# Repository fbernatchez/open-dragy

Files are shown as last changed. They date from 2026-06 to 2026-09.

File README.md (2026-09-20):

# 🏁 OpenDragy

OpenDragy is a high-precision, open-source vehicle performance timer that measures acceleration, speed intervals, and distances. It combines custom **ESP32-S3 firmware** reading a 10Hz GPS and a BMI160 accelerometer with a sleek, dark-themed **Flutter companion app** over Bluetooth Low Energy (BLE).

---

## ✨ Features

* **High-Precision Telemetry (10Hz)**: Receives and parses binary **UBX-NAV-PVT** packets from the u-blox GPS module 10 times per second, providing precise speed, position, and satellite count directly from the chip's internal navigation solution.
* **Real-Time G-Force Telemetry**: Streams live accelerometer data at 100Hz from the onboard BMI160 IMU for instant G-force mapping and post-run acceleration curve analysis.
* **Flexible Mounting & 3D Attitude Alignment**: Mount the enclosure facing any direction (0–359°) and on sloped surfaces (windshield mounts, angled dashboards, cup holders). Continuous 3D gravity vector tracking ($A_x, A_y, A_z$) projects acceleration onto the true horizontal plane orthogonal to gravity, preventing cosine attenuation and eliminating pitch/roll slope leakage.
* **Interactive Mounting Preview**: An intuitive graphical setup dialog renders a top-down view of the OpenDragy enclosure rotating dynamically over a neutral compass rose with 0°, 90°, 180°, 270° quick presets and 1° fine-tuning.
* **Zero-Crossing Interpolation**: Interpolates the exact start time (down to the millisecond) between the last stationary tick and the first launch tick, guaranteeing highly accurate launch timings.
* **Auto-Armed Launch Control**: Automatically starts recording when speed exceeds `3.0 km/h` to bypass GPS drift/wandering, auto-stops when stationary, and auto-disarms upon completion.
* **Voice Announcements (TTS) & Audio Recording**: Real-time spoken announcements for run starts, milestone completions, and trap speeds. Optional cabin audio recording lets you capture exhaust notes synced directly with your telemetry.
* **Wireless OTA Firmware Updates**: Wirelessly check for, download, and flash ESP32-S3 firmware updates directly over BLE from the companion app without opening the case or plugging in USB.
* **Wakelock Integration**: Intelligently keeps your device screen awake and active during armed and ongoing runs, so you never miss your telemetry.
* **Aesthetic Companion App**: Built with Flutter featuring a premium OLED black design with Neon Amber and Neon Green styling, utilizing the Inter font family.
* **Garage & Fleet Management**: Track multiple vehicles locally and link performance runs to specific cars or bikes.
* **Automated Weather Logging**: Uses coordinates from the GPS at the time of the run to fetch ambient temperature, altitude, and relative humidity from the free Open-Meteo API.
* **Run Database & Analytics**: View historical runs with detailed interactive charts showing speed curves, G-force mapping, and elevation/slope profiles to ensure valid runs.

---

## 🏎️ Supported Run Types & Targets

### Drag Mode (From a standstill)
* **Distances**: 60ft, 330ft, 1/8 mile, 1000 ft, 1/4 mile, 1/2 mile (includes trap speed calculations)
* **Speeds**: 0-60 mph, 0-100 km/h, 0-130 mph, 0-200 km/h
* **NHRA Mode**: Optional 1-ft rollout subtraction and 66ft average trap speed calculation to match official track times.

### Interval Mode (Speed-to-Speed)
* **Standard Ranges**:
  * **Imperial**: 0-60 mph, 0-100 mph, 50-75 mph, 60-100 mph, 60-130 mph, 0-130 mph
  * **Metric**: 0-100 km/h, 0-160 km/h, 80-120 km/h, 100-160 km/h, 100-200 km/h, 0-200 km/h
* **Custom Ranges**: Define your own starting and ending speeds (e.g., 100-150 km/h, 80-120 km/h) in both Metric and Imperial units.

---

## 🛠️ Hardware Setup

The hardware unit runs on an **ESP32-S3** microcontroller that interfaces with a high-speed GPS module and a 6-axis IMU sensor.

For a 3D-printable case for the OpenDragy hardware, check out the [OpenDragy Printables page](https://www.printables.com/model/1762658-opendragy-open-source-high-precision-10hz-gps-perf).

### 📋 Bill of Materials (BOM)
1. **ESP32-S3 Mini Development Board** (or similar ESP32-S3 board)
2. **QUESCAN G10A-F30 UBX M10 GPS Module** (supporting 10-25Hz refresh rates and configured at 115200 baud)
3. **BMI160 Accelerometer/Gyroscope IMU Module** (connected via I2C)

### 🔌 Pin Connections
Connect the components to your ESP32-S3 board using the following pin mapping defined in the firmware:

| Component | Component Pin | ESP32-S3 Pin | Notes |
| :--- | :--- | :--- | :--- |
| **BMI160 IMU** | VCC | 3.3V | Power supply |
| | GND | GND | Ground |
| | SDA | **GPIO 1** | I2C Data line |
| | SCL | **GPIO 2** | I2C Clock line |
| **u-blox GPS** | VCC | 3.3V or 5V | Power supply (depending on module) |
| | GND | GND | Ground |
| | TX | **GPIO 4** | Connects to ESP32-S3 RX (UART1) |
| | RX | **GPIO 5** | Connects to ESP32-S3 TX (UART1) |

---

## 💾 Firmware Installation

The ESP32-S3 firmware is located in [`OpenDragy.ino`](OpenDragy.ino).

1. Install the Arduino IDE or VS Code with the PlatformIO extension.
2. Install the **ESP32 board support package** if using Arduino IDE.
3. Install the library dependencies:
   * **DFRobot_BMI160** library (for interfacing with the IMU)
   * **BLE** stack (built-in for ESP32/ESP32-S3)
4. Open [`OpenDragy.ino`](OpenDragy.ino).
5. Compile and flash the code to your ESP32-S3.
6. The device will boot and start broadcasting a BLE service named `OpenDragy`.

---

## 📱 Mobile App Setup

The companion application is written in Flutter and is located in the root directory.

### Prerequisites
* Flutter SDK (v3.11.5 or newer recommended)
* Android Studio (for Android build) / Xcode (for iOS build, macOS required)
* A physical device with Bluetooth enabled (BLE is not supported on most simulators/emulators)

### Getting Started

1. Get packages and dependencies:
   ```bash
   flutter pub get
   ```

2. Run the application on a connected device:
   ```bash
   flutter run --release
   ```
   *(Running in release mode is recommended for accurate performance and UI timing).*

---

## 📂 Code Structure

* [`OpenDragy.ino`](OpenDragy.ino): Microcontroller C++ firmware for reading binary UBX-NAV-PVT packets over UART & I2C IMU data and transmitting over BLE.
* [`lib/main.dart`](lib/main.dart): Main application entry point, sets up global theme and screen routing.
* [`lib/services/physics_engine.dart`](lib/services/physics_engine.dart): Advanced physics computations (trapezoidal integration, zero-crossing interpolation, speed interval timing).
* [`lib/services/ble_service.dart`](lib/services/ble_service.dart): BLE scanner and stream listener that parses binary UBX packets & IMU data.
* [`lib/providers/dragy_provider.dart`](lib/providers/dragy_provider.dart): Core state provider coordinating Bluetooth events, GPS/IMU data processing, 3D attitude alignment, run logic, settings, and database saves.
* [`lib/services/history_service.dart`](lib/services/history_service.dart): Manages local saving and retrieval of historical run logs.
* [`lib/services/weather_service.dart`](lib/services/weather_service.dart): Integration with Open-Meteo API to log run-time environment data.
* [`lib/services/garage_service.dart`](lib/services/garage_service.dart): Manages local storage of vehicle profiles (cars, bikes) for fleet management.
* [`lib/services/settings_service.dart`](lib/services/settings_service.dart): Handles user preferences such as unit toggles (Metric/Imperial) and app settings.
* [`lib/services/tts_service.dart`](lib/services/tts_service.dart): Voice announcements (TTS) for run starts, milestone completions, and trap speeds.
* [`lib/services/audio_recording_service.dart`](lib/services/audio_recording_service.dart): Cabin audio recording synchronized with telemetry during performance runs.
* [`lib/services/firmware_service.dart`](lib/services/firmware_service.dart): Manages ESP32-S3 firmware version checks and wireless OTA updates over BLE.
* [`lib/widgets/box_pivot_preview.dart`](lib/widgets/box_pivot_preview.dart): Interactive 360° enclosure orientation dialog with rotating top-down visual preview, presets, and fine slider.
* [`lib/screens/dashboard_screen.dart`](lib/screens/dashboard_screen.dart): Live telemetry display, speedometer, Bluetooth controls, and active timer stats.
* [`lib/screens/run_history_screen.dart`](lib/screens/run_history_screen.dart): Displays the history of all recorded runs and allows filtering or selecting runs to view details.
* [`lib/screens/run_detail_screen.dart`](lib/screens/run_detail_screen.dart): Post-run analysis, graphs, G-force curves, and slope validations.
* [`lib/screens/garage_screen.dart`](lib/screens/garage_screen.dart): Interface for adding, editing, and selecting vehicles.
* [`lib/screens/settings_screen.dart`](lib/screens/settings_screen.dart): UI for configuring app preferences, box pivot orientation, audio settings, and OTA firmware.

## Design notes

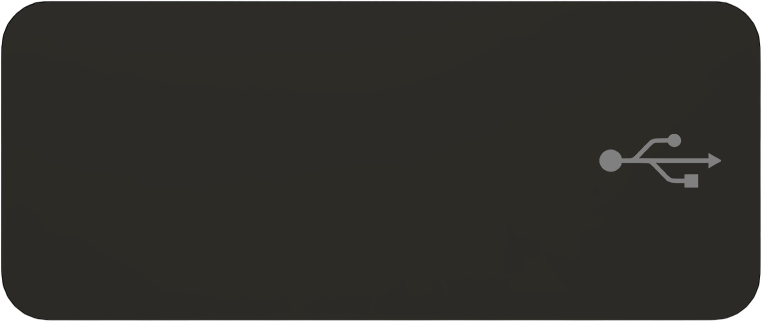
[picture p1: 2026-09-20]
assets/images/box-top-view.png

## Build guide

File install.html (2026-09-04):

# Flash OpenDragy

Connect your ESP32-S3 via USB, select a firmware version, and click Install to flash your device directly from the browser.

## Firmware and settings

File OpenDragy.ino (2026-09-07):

#include <Arduino.h>
#include <BLE2902.h>
#include <BLEDevice.h>
#include <BLEServer.h>
#include <BLEUtils.h>
#include <DFRobot_BMI160.h>
#include <HardwareSerial.h>
#include <Update.h>
#include <Wire.h>

HardwareSerial UART(1);
DFRobot_BMI160 bmi160;

BLEServer *pServer = NULL;
BLECharacteristic *pTxCharacteristic = NULL;
BLECharacteristic *pImuCharacteristic = NULL;

volatile bool deviceConnected = false;
volatile bool oldDeviceConnected = false;
bool imuReady = false;
bool otaRebootPending = false;

#define SERVICE_UUID "6e400001-b5a3-f393-e0a9-e50e24dcca9e"
#define CHARACTERISTIC_UUID_RX "6e400002-b5a3-f393-e0a9-e50e24dcca9e"
#define CHARACTERISTIC_UUID_TX "6e400003-b5a3-f393-e0a9-e50e24dcca9e"
#define CHARACTERISTIC_UUID_IMU "6e400004-b5a3-f393-e0a9-e50e24dcca9e"
#define CHARACTERISTIC_UUID_VERSION "6e400005-b5a3-f393-e0a9-e50e24dcca9e"
#define CHARACTERISTIC_UUID_OTA_CTRL "6e400006-b5a3-f393-e0a9-e50e24dcca9e"
#define CHARACTERISTIC_UUID_OTA_DATA "6e400007-b5a3-f393-e0a9-e50e24dcca9e"

#define FIRMWARE_VERSION "1.0.3"

// RTOS Queue for GPS packets
QueueHandle_t gpsQueue;

class MyServerCallbacks : public BLEServerCallbacks {
  void onConnect(BLEServer *pServer) {
    deviceConnected = true;
    pServer->updateConnParams(pServer->getConnId(), 0x06, 0x12, 0, 100);
  };
  void onDisconnect(BLEServer *pServer) { deviceConnected = false; }
};

class MyCallbacks : public BLECharacteristicCallbacks {
  void onWrite(BLECharacteristic *pCharacteristic) {
    String rxValue = pCharacteristic->getValue();
    if (rxValue.length() > 0) {
      UART.write((uint8_t *)rxValue.c_str(), rxValue.length());
    }
  }
};

class OtaCtrlCallbacks : public BLECharacteristicCallbacks {
  void onWrite(BLECharacteristic *pCharacteristic) {
    String rxValue = pCharacteristic->getValue();
    if (rxValue.length() > 0) {
      uint8_t cmd = rxValue[0];
      if (cmd == 0x00) { // Start OTA
        if (rxValue.length() >= 5) {
          uint32_t fwSize = rxValue[1] | (rxValue[2] << 8) |
                            (rxValue[3] << 16) | (rxValue[4] << 24);
          Serial.printf("OTA Start, size: %d\n", fwSize);
          if (!Update.begin(fwSize, U_FLASH)) {
            Serial.println("OTA Update.begin failed");
          }
        }
      } else if (cmd == 0x01) { // End OTA
        Serial.println("OTA End");
        if (Update.end(true)) {
          Serial.println("OTA Success! Rebooting...");
          otaRebootPending = true;
        } else {
          Serial.printf("OTA Error: %s\n", Update.errorString());
        }
      }
    }
  }
};

class OtaDataCallbacks : public BLECharacteristicCallbacks {
  void onWrite(BLECharacteristic *pCharacteristic) {
    String rxValue = pCharacteristic->getValue();
    if (rxValue.length() > 0) {
      if (Update.write((uint8_t *)rxValue.c_str(), rxValue.length()) !=
          rxValue.length()) {
        Serial.println("OTA Write failed");
      }
    }
  }
};

void setupBLE() {
  BLEDevice::init("OpenDragy");
  pServer = BLEDevice::createServer();
  pServer->setCallbacks(new MyServerCallbacks());
  BLEService *pService = pServer->createService(SERVICE_UUID);

  BLECharacteristic *pVersionCharacteristic = pService->createCharacteristic(
      CHARACTERISTIC_UUID_VERSION, BLECharacteristic::PROPERTY_READ);
  pVersionCharacteristic->setValue(FIRMWARE_VERSION);

  pTxCharacteristic = pService->createCharacteristic(
      CHARACTERISTIC_UUID_TX, BLECharacteristic::PROPERTY_NOTIFY);
  pTxCharacteristic->addDescriptor(new BLE2902());

  pImuCharacteristic = pService->createCharacteristic(
      CHARACTERISTIC_UUID_IMU, BLECharacteristic::PROPERTY_NOTIFY);
  pImuCharacteristic->addDescriptor(new BLE2902());

  BLECharacteristic *pRxCharacteristic = pService->createCharacteristic(
      CHARACTERISTIC_UUID_RX, BLECharacteristic::PROPERTY_WRITE);
  pRxCharacteristic->setCallbacks(new MyCallbacks());

  BLECharacteristic *pOtaCtrlCharacteristic = pService->createCharacteristic(
      CHARACTERISTIC_UUID_OTA_CTRL, BLECharacteristic::PROPERTY_WRITE);
  pOtaCtrlCharacteristic->setCallbacks(new OtaCtrlCallbacks());

  BLECharacteristic *pOtaDataCharacteristic = pService->createCharacteristic(
      CHARACTERISTIC_UUID_OTA_DATA,
      BLECharacteristic::PROPERTY_WRITE | BLECharacteristic::PROPERTY_WRITE_NR);
  pOtaDataCharacteristic->setCallbacks(new OtaDataCallbacks());

  pService->start();
  BLEAdvertising *pAdvertising = BLEDevice::getAdvertising();
  pAdvertising->addServiceUUID(SERVICE_UUID);
  pAdvertising->setScanResponse(true);
  pAdvertising->setMinPreferred(0x06);
  pAdvertising->setMaxPreferred(0x12);
  BLEDevice::startAdvertising();
}

// Function to send a formatted UBX packet
void sendUBX(uint8_t cls, uint8_t id, const uint8_t *payload, uint16_t len) {
  UART.write(0xB5);
  UART.write(0x62);
  UART.write(cls);
  UART.write(id);
  UART.write(len & 0xFF);
  UART.write((len >> 8) & 0xFF);

  uint8_t ck_a = 0, ck_b = 0;
  ck_a += cls;
  ck_b += ck_a;
  ck_a += id;
  ck_b += ck_a;
  ck_a += (len & 0xFF);
  ck_b += ck_a;
  ck_a += ((len >> 8) & 0xFF);
  ck_b += ck_a;

  for (uint16_t i = 0; i < len; i++) {
    UART.write(payload[i]);
    ck_a += payload[i];
    ck_b += ck_a;
  }
  UART.write(ck_a);
  UART.write(ck_b);
}

void setupGPS() {
  Serial.println("Configuring u-blox GPS (Auto-baud & UBX NAV-PVT)...");

  // Connect at default u-blox baud rate to send configuration
  UART.begin(38400, SERIAL_8N1, 4, 5);
  delay(200);

  // CFG-VALSET Payload for u-blox M10 (Layer 1 = RAM)
  // 1. CFG-UART1-BAUDRATE = 115200 (0x0001C200) -> Key: 0x40520001
  uint8_t baudPayload[] = {
      0x00, 0x01, 0x00, 0x00, // Version 0, Layer 1 (RAM), Reserved
      0x01, 0x00, 0x52, 0x40, // Key: CFG-UART1-BAUDRATE
      0x00, 0xC2, 0x01, 0x00  // Value: 115200
  };
  sendUBX(0x06, 0x8A, baudPayload, sizeof(baudPayload));
  delay(100);

  // Switch ESP32 UART to the new 115200 baud
  UART.end();
  UART.begin(115200, SERIAL_8N1, 4, 5);
  delay(200);

  // 2. CFG-RATE-MEAS = 100ms (10Hz) -> Key: 0x30210001
  // 3. CFG-NAVSPG-DYNMODEL = 4 (Automotive) -> Key: 0x20110021
  // 4. CFG-MSGOUT-UBX_NAV_PVT_UART1 = 1 -> Key: 0x20910007
  // 5. Disable NMEA outputs on UART1
  uint8_t configPayload[] = {
      0x00, 0x01, 0x00, 0x00, // Version 0, Layer 1 (RAM), Reserved

      0x01, 0x00, 0x21, 0x30, // Key: CFG-RATE-MEAS
      0x64, 0x00,             // Value: 100ms

      0x21, 0x00, 0x11, 0x20, // Key: CFG-NAVSPG-DYNMODEL
      0x04,                   // Value: Automotive

      0x07, 0x00, 0x91, 0x20, // Key: CFG-MSGOUT-UBX_NAV_PVT_UART1
      0x01,                   // Value: 1 (Enable)

      0xBA, 0x00, 0x91, 0x20, // Key: CFG-MSGOUT-NMEA_ID_GGA_UART1
      0x00,                   // Value: 0 (Disable)

      0xC9, 0x00, 0x91, 0x20, // Key: CFG-MSGOUT-NMEA_ID_GLL_UART1
      0x00,

      0xC0, 0x00, 0x91, 0x20, // Key: CFG-MSGOUT-NMEA_ID_GSA_UART1
      0x00,

      0xC5, 0x00, 0x91, 0x20, // Key: CFG-MSGOUT-NMEA_ID_GSV_UART1
      0x00,

      0xAC, 0x00, 0x91, 0x20, // Key: CFG-MSGOUT-NMEA_ID_RMC_UART1
      0x00,

      0xB1, 0x00, 0x91, 0x20, // Key: CFG-MSGOUT-NMEA_ID_VTG_UART1
      0x00};
  sendUBX(0x06, 0x8A, configPayload, sizeof(configPayload));
  delay(100);

  Serial.println("GPS configuration sent.");
}

// RTOS Task: Read UART and push full UBX packets to Queue
void gpsReadTask(void *parameter) {
  uint8_t buffer[128];
  uint16_t idx = 0;
  uint8_t state = 0;
  uint16_t expectedLen = 0;

  while (1) {
    while (UART.available() > 0) {
      uint8_t c = UART.read();

      switch (state) {
      case 0:
        if (c == 0xB5) {
          buffer[0] = c;
          state = 1;
          idx = 1;
        }
        break;
      case 1:
        if (c == 0x62) {
          buffer[1] = c;
          state = 2;
          idx = 2;
        } else {
          state = 0;
        }
        break;
      case 2: // Class
        buffer[idx++] = c;
        state = 3;
        break;
      case 3: // ID
        buffer[idx++] = c;
        state = 4;
        break;
      case 4: // Length LSB
        buffer[idx++] = c;
        expectedLen = c;
        state = 5;
        break;
      case 5: // Length MSB
        buffer[idx++] = c;
        expectedLen |= (c << 8);
        // NAV-PVT payload is usually 92 or 100 bytes. Reject lengths that are
        // too large.
        if (expectedLen > 110) {
          state = 0;
        } else {
          state = 6;
        }
        break;
      case 6: // Payload
        buffer[idx++] = c;
        if (idx ==
            expectedLen + 6) { // header(2) + cls(1) + id(1) + len(2) + payload
          state = 7;
        }
        break;
      case 7: // Checksum A
        buffer[idx++] = c;
        state = 8;
        break;
      case 8: // Checksum B
        buffer[idx++] = c;

        // Verify Checksum
        uint8_t ck_a = 0, ck_b = 0;
        for (uint16_t i = 2; i < idx - 2; i++) {
          ck_a += buffer[i];
          ck_b += ck_a;
        }

        if (ck_a == buffer[idx - 2] && ck_b == buffer[idx - 1]) {
          // Check if it's NAV-PVT (Class 0x01, ID 0x07)
          if (buffer[2] == 0x01 && buffer[3] == 0x07) {
            // Send to FIFO queue, do not block if full (we drop the oldest or
            // drop this one)
            xQueueSend(gpsQueue, buffer, 0);
          }
        }
        state = 0; // Reset for next packet
        break;
      }
    }
    vTaskDelay(pdMS_TO_TICKS(5)); // Yield to other tasks
  }
}

// RTOS Task: Read from Queue and send BLE Notifications
void bleNotifyTask(void *parameter) {
  uint8_t buffer[128];
  while (1) {
    if (xQueueReceive(gpsQueue, buffer, portMAX_DELAY) == pdTRUE) {
      if (deviceConnected && pTxCharacteristic) {
        uint16_t len = buffer[4] | (buffer[5] << 8);
        uint16_t totalLen =
            len + 8; // Include header, class, id, length, payload, checksum

        // Notify Flutter app
        pTxCharacteristic->setValue(buffer, totalLen);
        pTxCharacteristic->notify();
      }
    }
  }
}

// RTOS Task: IMU polling
void imuTask(void *parameter) {
  float filteredAx = 0.0f;
  float filteredAy = 0.0f;
  float filteredAz = 0.0f;
  const float alpha =
      0.2f; // EMA smoothing factor (0.0 to 1.0). Lower is smoother.
  bool filterInitialized = false;

  while (1) {
    if (deviceConnected && imuReady) {
      int16_t accelGyro[6] = {0};
      bmi160.getAccelGyroData(accelGyro);

      if (!filterInitialized) {
        filteredAx = accelGyro[3];
        filteredAy = accelGyro[4];
        filteredAz = accelGyro[5];
        filterInitialized = true;
      } else {
        filteredAx = (alpha * accelGyro[3]) + ((1.0f - alpha) * filteredAx);
        filteredAy = (alpha * accelGyro[4]) + ((1.0f - alpha) * filteredAy);
        filteredAz = (alpha * accelGyro[5]) + ((1.0f - alpha) * filteredAz);
      }

      char imuData[32];
      snprintf(imuData, sizeof(imuData), "%d,%d,%d\n", (int16_t)filteredAx,
               (int16_t)filteredAy, (int16_t)filteredAz);
      pImuCharacteristic->setValue((uint8_t *)imuData, strlen(imuData));
      pImuCharacteristic->notify();
    } else {
      filterInitialized = false; // Reset filter state on disconnect
    }
    vTaskDelay(pdMS_TO_TICKS(10)); // 100Hz IMU rate
  }
}

void setup() {
  Serial.begin(115200);
  delay(1000);
  Serial.println("--- OpenDragy Firmware Boot ---");

  Serial.println("Initializing I2C Bus...");
  int attempts = 0;
  int maxAttempts = 3;
  while (attempts < maxAttempts && !imuReady) {
    attempts++;
    Serial.printf("Connecting to BMI160: Attempt %d/%d...\n", attempts,
                  maxAttempts);
    Wire.end();
    Wire.begin(1, 2, 100000);
    delay(50);
    bmi160.softReset();
    delay(100);
    if (bmi160.I2cInit(0x69) == BMI160_OK) {
      Serial.println("-> BMI160 detected and initialized successfully.");
      imuReady = true;
    } else {
      Serial.println("-> Connection failed. Retrying...");
      if (attempts < maxAttempts) {
        delay(200);
      }
    }
  }

  if (!imuReady) {
    Serial.println("[CRITICAL ERROR] BMI160 hardware not responding. Running "
                   "in GPS-only mode.");
  }

  setupGPS();

  Serial.println("Initializing BLE Stack...");
  setupBLE();

  gpsQueue = xQueueCreate(10, 128);

  xTaskCreatePinnedToCore(gpsReadTask, "GPS_Read", 4096, NULL, 2, NULL, 1);
  xTaskCreatePinnedToCore(bleNotifyTask, "BLE_Notify", 4096, NULL, 1, NULL,
                          0); // Run on core 0 with BLE stack
  xTaskCreatePinnedToCore(imuTask, "IMU_Task", 4096, NULL, 1, NULL, 1);

  Serial.println("=== SYSTEM READY: Awaiting BLE connection ===");
}

void loop() {
  if (otaRebootPending) {
    delay(1000);
    ESP.restart();
  }

  if (!deviceConnected && oldDeviceConnected) {
    delay(500);
    pServer->getAdvertising()->start();
    oldDeviceConnected = false;
  }
  if (deviceConnected && !oldDeviceConnected) {
    oldDeviceConnected = true;
  }
  vTaskDelay(pdMS_TO_TICKS(100)); // Sleep loop task
}

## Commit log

2026-06-07 Refactor race target to use getTime callbacks instead of hardcoded switches
2026-06-10 Harden ESP32 firmware (thread safety, static GPS buffer, IMU fallback)
2026-06-13 Bump version to 1.0.2-beta.1+23 and resolve packet loss/drift [skip ci]
    [OpenDragy.ino]
2026-06-22 docs: Update hardware BOM to reflect ESP32-S3, QUESCAN G10A-F30, and BMI160
2026-06-23 Add SerialToSerial and Pin Numbering instructions
2026-06-24 docs: update README with Printables link
2026-07-31 feat: Add TTS announcements and run history enhancements
    - Integrated flutter_tts for milestone announcements (queue mode).
    - Configured TTS to speak customized text values instead of raw numbers.
    - Added unit-aware and explicit phrase filtering for TTS triggers.
    - Replaced mocked data with dynamic run history filtering by vehicle.
    - Added functionality to edit vehicle association for past runs.
    - Added auto-capitalization to Garage screen inputs.
    - Ignored .vscode in .gitignore.
2026-08-12 test: fix physics engine test failures caused by outlier filter
2026-08-13 Refactor telemetry chart audio player and UI
    - Fix playback state machine to reload MediaPlayer source on completion
    - Restore missing audio play button UI
    - Optimize chart scrubber time interpolation
    - Bump version to 1.0.12-beta.2+52
2026-08-27 feat: migrate to binary UBX and FreeRTOS architecture
    - Refactored ESP32 firmware to use FreeRTOS tasks and a FIFO queue
    - Migrated from NMEA to binary UBX NAV-PVT for high precision 10Hz GPS
    - Replaced Flutter app NMEA parser with native UBX decoder using iTOW timestamps
    - Implemented GPS auto-configuration on boot, removing need for manual u-center configuration
    - Bumped version to 1.1.0-beta.1
    [OpenDragy.ino]
2026-08-27 chore: add JSON export button for debugging runs
2026-08-28 feat: add BLE OTA firmware update support for ESP32
2026-09-04 fix: Conserve 100Hz IMU energy between GPS physics ticks and use event-driven modal closure
2026-09-07 Fix metric/imperial history filtering, hide up-to-date firmware update button, and replace artificial Dart G-force delay with ESP32 hardware EMA filter
    [OpenDragy.ino]
2026-09-08 Refactor domain enums to type-safe enums and consolidate firmware update dialog
    - Introduce RunMode enum and replace stringly-typed run modes and units
    - Remove unused parameter warning in GarageScreen
    - Consolidate firmware update prompt and flashing into a single unified dialog
    - Centralize firmware version comparison and minimum version checks in FirmwareService
    - Add prominent warning not to unplug device during firmware updates
2026-09-08 Configure native camera-app audio recording
2026-09-15 fix: pin objective_c to 9.4.1 and calculate speeds dynamically from telemetry
2026-09-18 feat: decouple hero timer and respect test visibility settings
2026-09-18 fix: support standing-start interval NHRA rules and filter custom distance tests by unit system
2026-09-18 fix: synchronize active interval test when switching speed units
2026-09-20 feat: add box pivot orientation with 3D gravity leveling and visual preview
    - Add configurable box pivot orientation (0-359 deg) with presets and fine-tuning slider
    - Add visual preview dialog with interactive rotating top-down render on a neutral compass ring
    - Implement 3D attitude leveling projecting acceleration onto the horizontal plane orthogonal to gravity
    - Instant 1st-frame gravity seeding and continuous cruising/stationary EMA tracking
    - Add coordinate transformation and mounting tilt test coverage
2026-09-24 fix: clamp run distance, telemetry graph and stats to test finish time
2026-10-14 feat(ux): ui, navigation, and theme improvements
    - Adopt 3-tab bottom navigation: Meter, History, and Settings
    - Move Garage access to Dashboard vehicle pill and Settings menu
    - Centralize app bar, dialog, bottom sheet, tab bar, and navigation bar themes
    - Introduce AppTheme with AppColors ThemeExtension and context.colors extension
    - Add System / Dark / Light theme switch mode with persistent settings
    - Add GPS telemetry popup modal accessible from AppBar satellite icon
    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
2026-10-14 refactor: decouple TelemetryProvider and centralize typography in AppTheme
    - Decouple high-frequency real-time metrics (speed, gForce, slope, altitude) into a dedicated TelemetryProvider
    - Keep DragyProvider focused on BLE connection, device state, and saved history
    - Adopt clean tabular Roboto typography for fixed-width telemetry readouts and open round zeros
    - Centralize app font definitions (font, numericFont, brandFont) in AppTheme
    - Eliminate hardcoded GoogleFonts references across all screens and widgets
